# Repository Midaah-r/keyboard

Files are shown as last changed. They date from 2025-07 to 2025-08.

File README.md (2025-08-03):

# keyboard

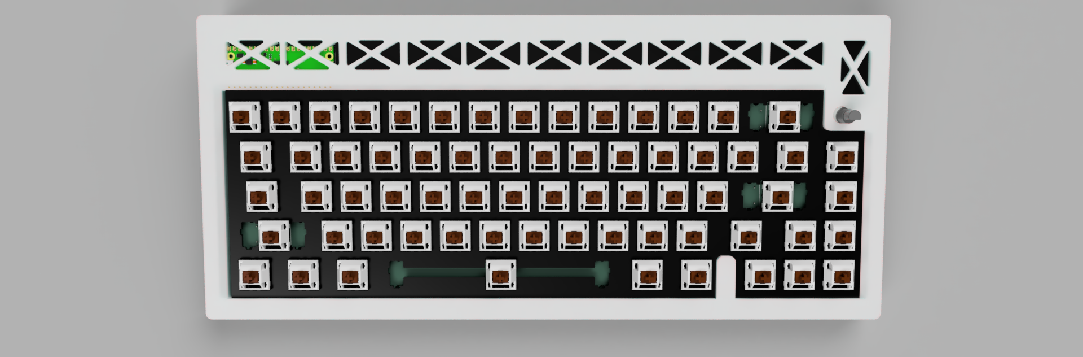
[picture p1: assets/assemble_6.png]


- compact & sleek
- 66x keys!
- Tweaked 65% layout
- 1x EC11 Rotary Encoder - For Volume, Brightness, etc
- powered by rp pico
- KMK firmware
- WOBBLY WIGGLY silkscreen

## Description

This is my first project of this scale and it was an amazing experience building this, i got to learn a lot! 

I would like to thank hackclub's hackapad tutorial, Joe Scotto and Google, you guys were my saviors.

The keyboard is a tweaked default 65% layout with one key replaced by a RE. The MCU used is Raspberry Pi Pico and the firmware used is kmk.

layout:

<image src="assets_journal/layout.png" width="400">

## PCB

**Dimensions**: 307mm x 125mm
Made inside of Kicad

| Schematic                 |
| ------------------------- |
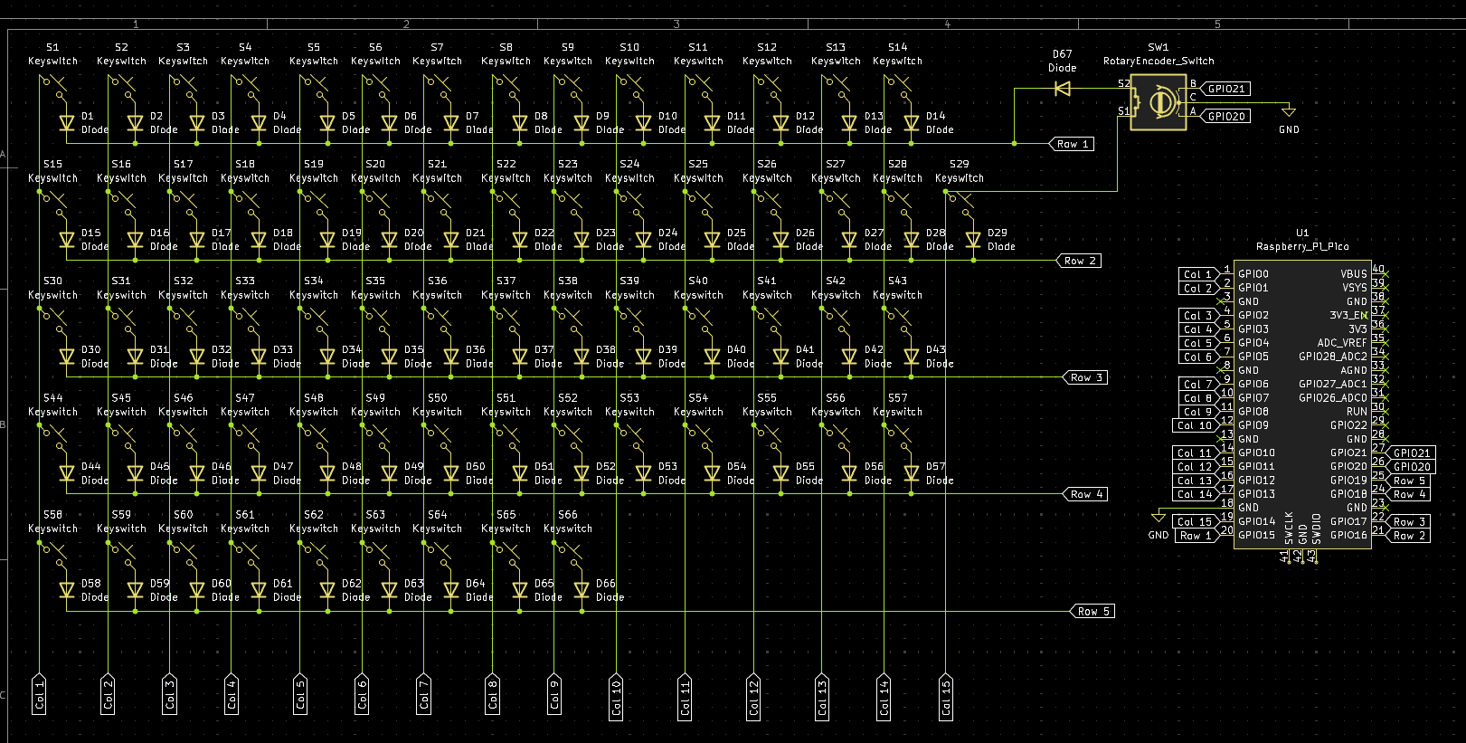
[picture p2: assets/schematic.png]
|  |

| Pcb                 |
| --------------------- |
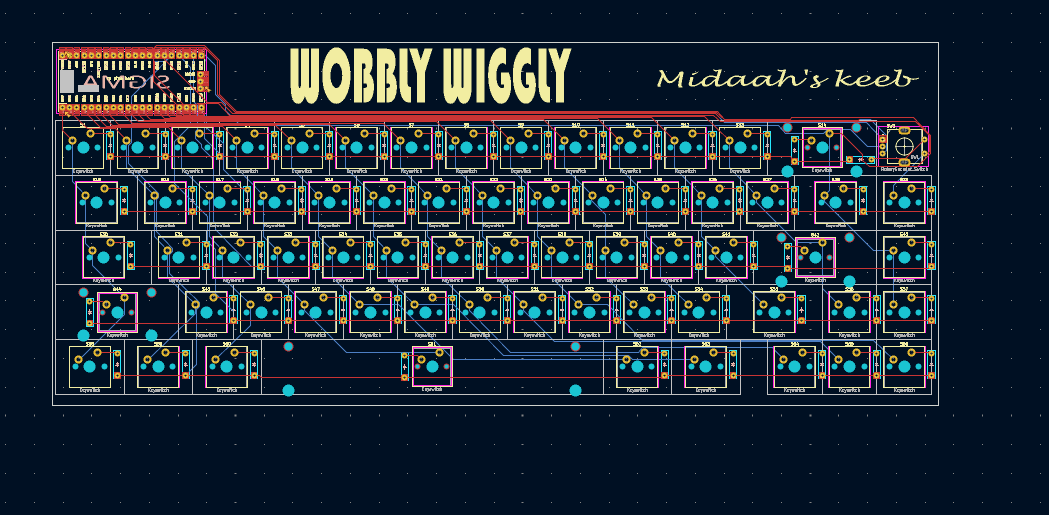
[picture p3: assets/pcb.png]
|  |

| Assembled - front             |
| ------------------------ |
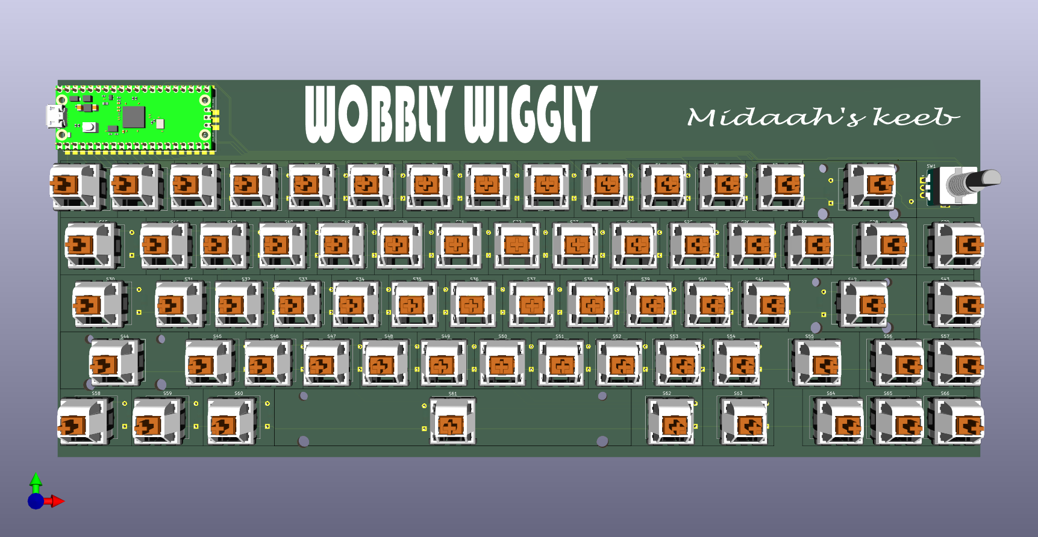
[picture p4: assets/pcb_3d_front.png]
|  |

| Assembled - Back               |
| ----------------------- |
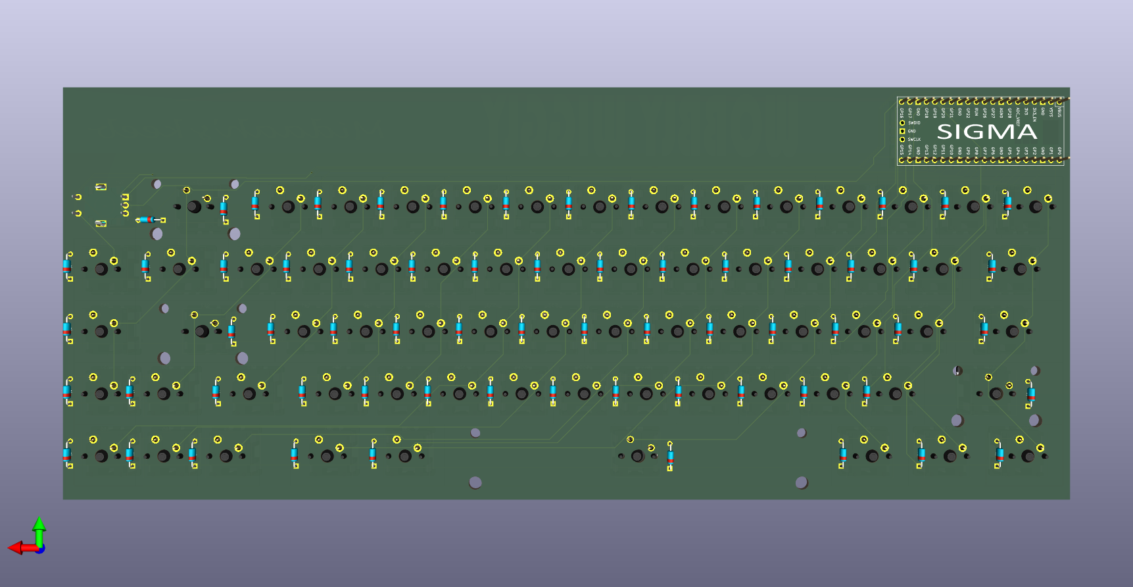
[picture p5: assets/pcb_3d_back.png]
|  |

## Case

The case was made in Fusion360.

bottom:

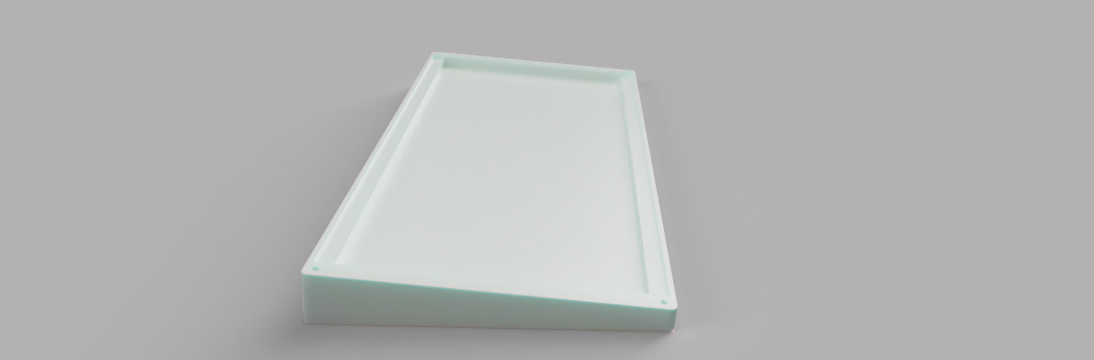
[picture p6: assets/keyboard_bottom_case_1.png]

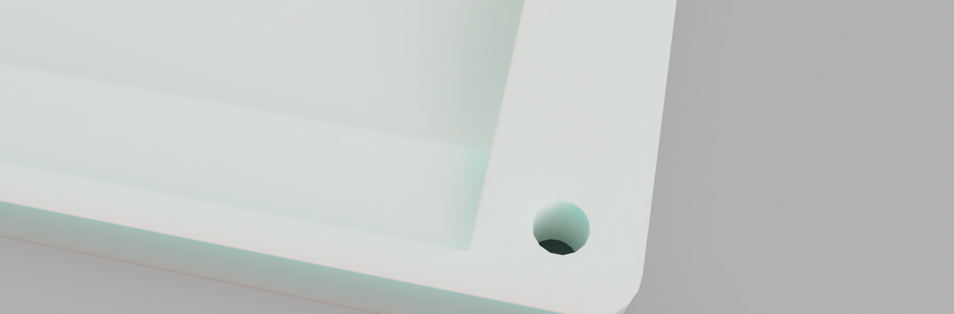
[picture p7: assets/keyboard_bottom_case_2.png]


plate:

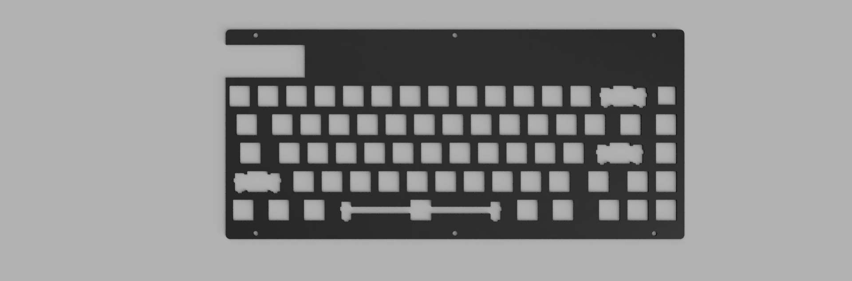
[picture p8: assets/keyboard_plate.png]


top:

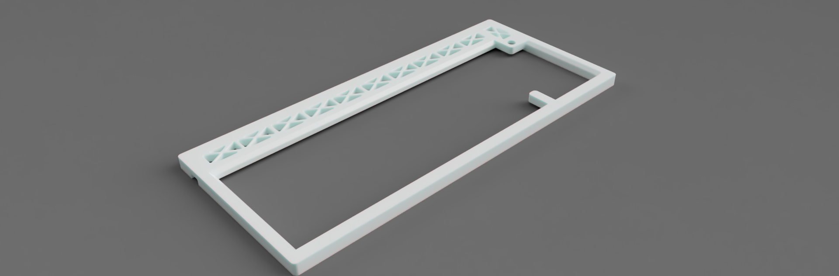
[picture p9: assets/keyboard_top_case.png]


## Assembly:

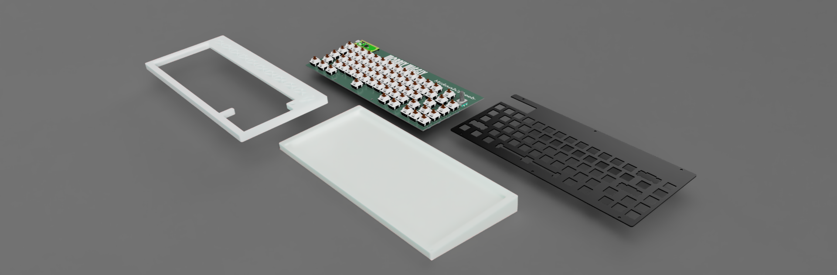
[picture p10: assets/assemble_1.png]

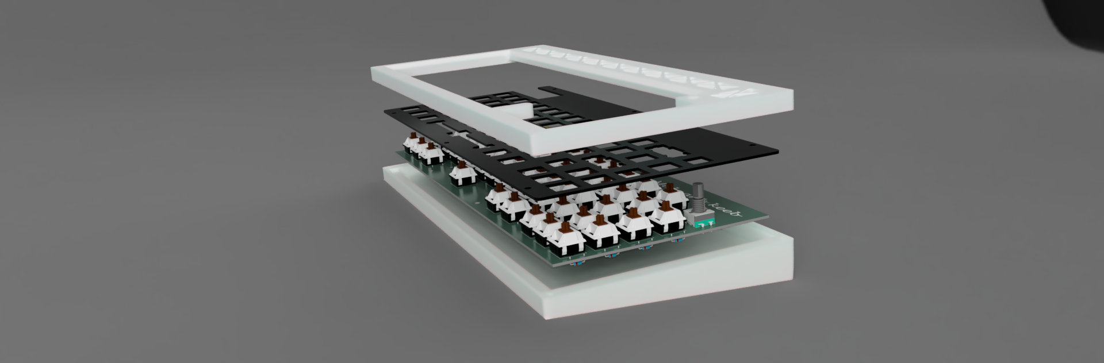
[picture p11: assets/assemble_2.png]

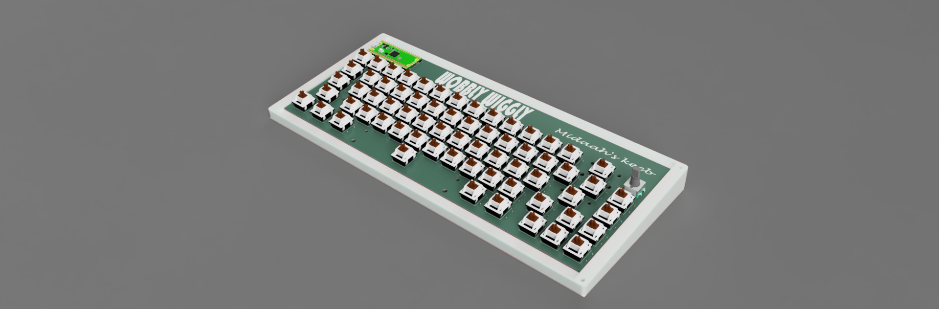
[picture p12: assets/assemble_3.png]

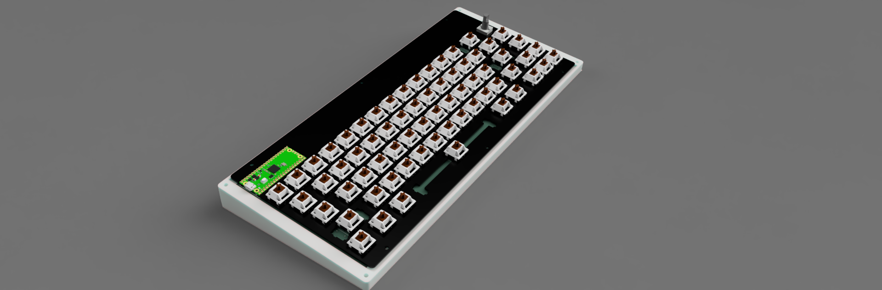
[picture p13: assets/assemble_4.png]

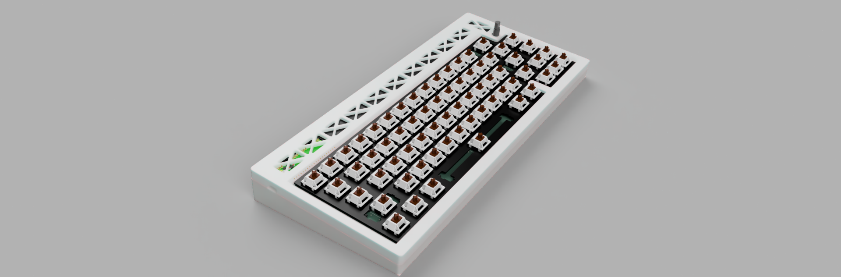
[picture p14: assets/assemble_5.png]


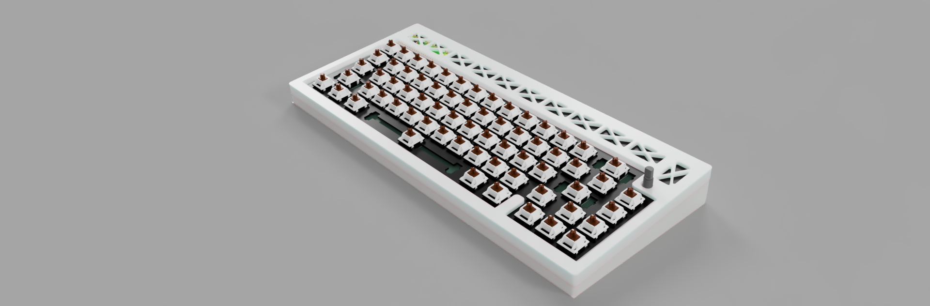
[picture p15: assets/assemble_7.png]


## Port: 

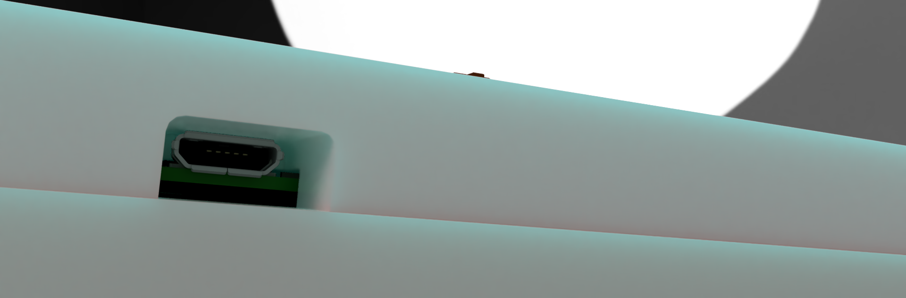
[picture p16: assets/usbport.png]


## BOM

| Name | Qty | Final Price - INR (USD) | Link |
| --- | --- | --- | --- |
| Gateron EF Grayish | 80  | 1560 ($17.79) | [here](https://neomacro.in/products/gateron-ef-grayish) |
| Cherry Profile PBT Keycaps | 1 | 1299 ($14.81) | [here](https://stackskb.com/store/veekos-gradient-keycaps-cherry-profile-135-keys/) |
| Durock Smokey Screw-In Stabilizers V2 (4+1 w/ 6.25u spacebar) | 1 | 1595 ($18.18) | [here](https://stackskb.com/store/durock-smokey-screw-in-stabilizers-v2/) |
| Diode 1N4148 Through - Hole | 80  | 176 ($2.01) | [here](https://roboticsdna.in/product/diode-1n4148/) |
| EC11 Rotary Encoder | 2 | 178 ($2.03) | [here](https://amzn.in/d/hVRxzij) |
| M3 x 16mm Allen Bolt | 25  | 170 ($1.94) | [here](https://www.amazon.in/RT-SENSE-Socket-Screws-Machine/dp/B0CX999P9J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) |
| M3 x 8mm Allen Bolt | 15  | 150 ($1.71) | [here](https://www.amazon.in/RT-SENSE-Socket-Screws-Machine/dp/B0CX99XY91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) |
| M3 x 6mm Heatset Insert | 12  | 100 ($1.14) | [here](https://www.amazon.in/M3X6-Brass-Threaded-Round-Insert/dp/B0BB86CQSJ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) |
| Raspberry Pi Pico | 1 | 384 ($4.38) | [here](https://roboticsdna.in/product/raspberry-pi-pico/) |
| Micro usb to type A cable | 2 | 580 ($6.62) | [here](https://www.amazon.in/amazon-basics-Braided-Charging-Transfer/dp/B0CH14KT9N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) |
| 4 in 1 USB hub | 1 | 200 ($2.28) | [here](https://www.amazon.in/Amazon-Multiport-Adapter-Aluminium-MacBook/dp/B0CFLT45KH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) |
| Lube (silicon dielectric grease) | 1 | 270 ($3.1) | [here](https://www.amazon.in/gp/product/B08R3NXT3B?smid=AYQOQ4F60DJ09&th=1) |
| PCB (White) | 5 | 4136.45 ($47.2) | [from jlcpcb](assets/jlcpcb_quote.png) | 
| Middle plate - 1 (White "production/MIDDLE.step") | 1 | 1276 ($14.56) | [from 3ding.in](assets/3ding_quote.png) |
| Bottom Case - 1 (White "production/BOTTOM.step") | 1 | Print Legion |
| Top Case - 1 (White "production/TOP.step") | 1 | Print Legion |
| Rotary Encoder Knob | 1 | Print Legion |
| Shipping (for diodes, MCU and Amazon) | - | 260.06 ($3) |

## Grand Total

The total sum of the parts comes to approximately inr 12335 ($141.5).

I have chosen air registered mail as the shipping option for jlcpcb as it's less likely to incurr customs thus actually being cheaper than other shipping providers.

PS: i have also included an additional USB hub and 2 microusb to type A cables because of the macropad and keyboard i wont have any space to plug the gadgets into my laptop

> **Note:** TOP and BOTTOM case parts in white, MIDDLE in black; PCB must be white.

Some componenets were ordered in packs due to unavailability (bolts, heatset inserts, etc), their prices may vary due to sales.

The final quote is subject to dollar-market trends

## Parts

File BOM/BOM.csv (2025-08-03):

Name | Qty | Final Price - INR (USD) | Link
Gateron EF Grayish | 80 | 1560 ($17.79) | https://neomacro.in/products/gateron-ef-grayish
Cherry Profile PBT Keycaps | 1 | 1299 ($14.81) | https://stackskb.com/store/veekos-gradient-keycaps-cherry-profile-135-keys/
Durock Smokey Screw-In Stabilizers V2 (4+1 w/ 6.25u spacebar) | 1 | 1595 ($18.18) | https://stackskb.com/store/durock-smokey-screw-in-stabilizers-v2/
Diode 1N4148 Through - Hole | 80 | 176 ($2.01) | https://roboticsdna.in/product/diode-1n4148/
EC11 Rotary Encoder | 2 | 178 ($2.03) | https://amzn.in/d/hVRxzij
M3 x 16mm Allen Bolt | 25 | 170 ($1.94) | https://www.amazon.in/RT-SENSE-Socket-Screws-Machine/dp/B0CX999P9J?s=industrial
M3 x 8mm Allen Bolt | 15 | 150 ($1.71) | https://www.amazon.in/RT-SENSE-Socket-Screws-Machine/dp/B0CX99XY91?s=industrial
M3 x 6mm Heatset Insert | 12 | 100 ($1.14) | https://www.amazon.in/M3X6-Brass-Threaded-Round-Insert/dp/B0BB86CQSJ?s=industrial
Raspberry Pi Pico | 1 | 384 ($4.38) | https://roboticsdna.in/product/raspberry-pi-pico/
Micro usb to type A cable | 2 | 580 ($6.62) | https://www.amazon.in/amazon-basics-Braided-Charging-Transfer/dp/B0CH14KT9N
4 in 1 USB hub | 1 | 200 ($2.28) | https://www.amazon.in/Amazon-Multiport-Adapter-Aluminium-MacBook/dp/B0CFLT45KH
Lube (silicon dielectric grease) | 1 | 270 ($3.1) | https://www.amazon.in/gp/product/B08R3NXT3B?smid=AYQOQ4F60DJ09&th=1
PCB (White) | 5 | 4136.45 ($47.2) | from jlcpcb
Middle plate - 1 (White "production/MIDDLE.step") | 1 | 1276 ($14.56) | from 3ding.in
Bottom Case - 1 (White "production/BOTTOM.step") | 1 | Print Legion
Top Case - 1 (White "production/TOP.step") | 1 | Print Legion
Rotary Encoder Knob | 1 | Print Legion
Shipping (for diodes | MCU and Amazon) | - | 260.6 ($3)

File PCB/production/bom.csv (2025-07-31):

Designator | Footprint | Quantity | Value | LCSC Part #
D1, D10, D11, D12, D13, D14, D15, D16, D17, D18, D19, D2, D20, D21, D22, D23, D24, D25, D26, D27, D28, D29, D3, D30, D31, D32, D33, D34, D35, D36, D37, D38, D39, D4, D40, D41, D42, D43, D44, D45, D46, D47, D48, D49, D5, D50, D51, D52, D53, D54, D55, D56, D57, D58, D59, D6, D60, D61, D62, D63, D64, D65, D66, D67, D7, D8, D9 | Diode_DO-35 | 67 | Diode
S1, S10, S11, S12, S13, S16, S17, S18, S19, S2, S20, S21, S22, S23, S24, S25, S26, S27, S29, S3, S31, S32, S33, S34, S35, S36, S37, S38, S39, S4, S40, S41, S43, S45, S46, S47, S48, S49, S5, S50, S51, S52, S53, S54, S56, S57, S6, S64, S65, S66, S7, S8, S9 | MX_PCB_1.00u | 53 | Keyswitch
S14 | SW_Cherry_MX_2.00u_PCB | 1 | Keyswitch
S15, S28 | MX_PCB_1.50u | 2 | Keyswitch
S30, S55 | MX_PCB_1.75u | 2 | Keyswitch
S42, S44 | SW_Cherry_MX_2.25u_PCB | 2 | Keyswitch
S58, S59, S60, S62, S63 | MX_PCB_1.25u | 5 | Keyswitch
S61 | SW_Cherry_MX_6.25u_PCB | 1 | Keyswitch
SW1 | RotaryEncoder_Alps_EC11E-Switch_Vertical_H20mm | 1 | RotaryEncoder_Switch
U1 | Raspberry_Pi_Pico | 1 | Raspberry_Pi_Pico

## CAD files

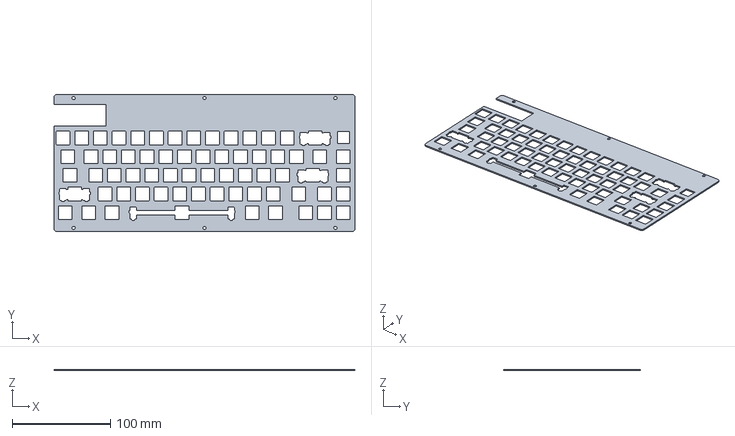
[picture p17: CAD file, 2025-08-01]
CAD/MIDDLE.step
307.0 x 140.0 x 1.50 mm

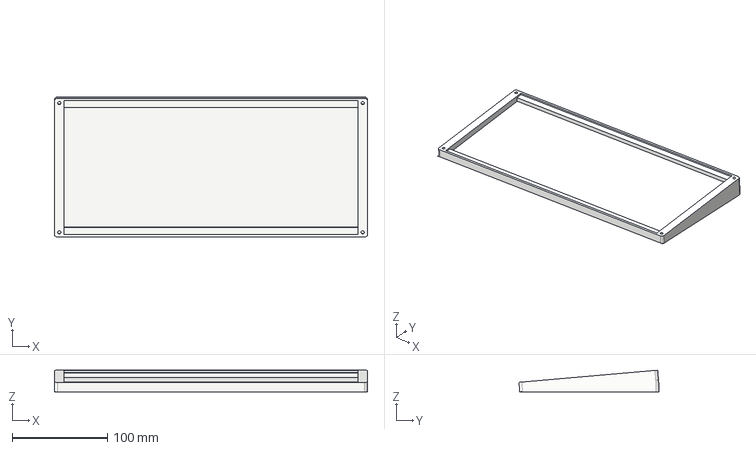
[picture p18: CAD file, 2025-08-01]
CAD/BOTTOM.step
328.0 x 146.9 x 22.7 mm

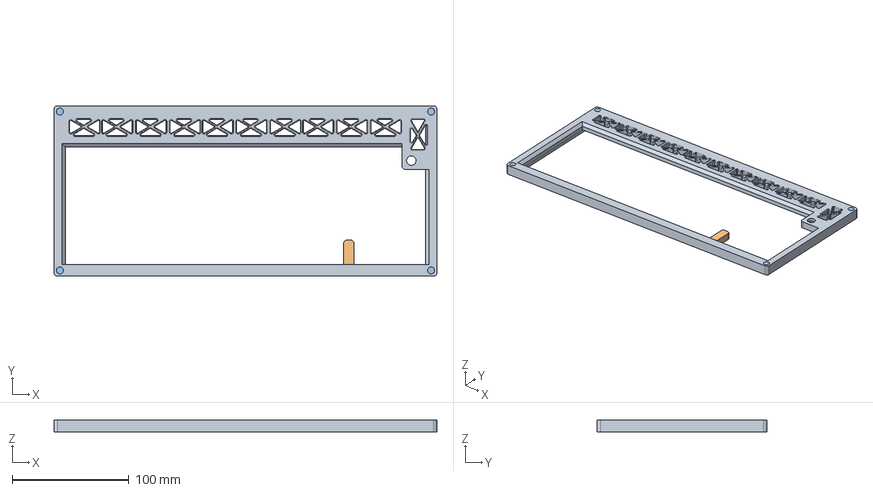
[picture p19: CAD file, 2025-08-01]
production/TOP.step
328.0 x 146.0 x 10.0 mm

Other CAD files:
CAD/STL/BOTTOM.stl
CAD/STL/MIDDLE.stl
CAD/STL/TOP.stl

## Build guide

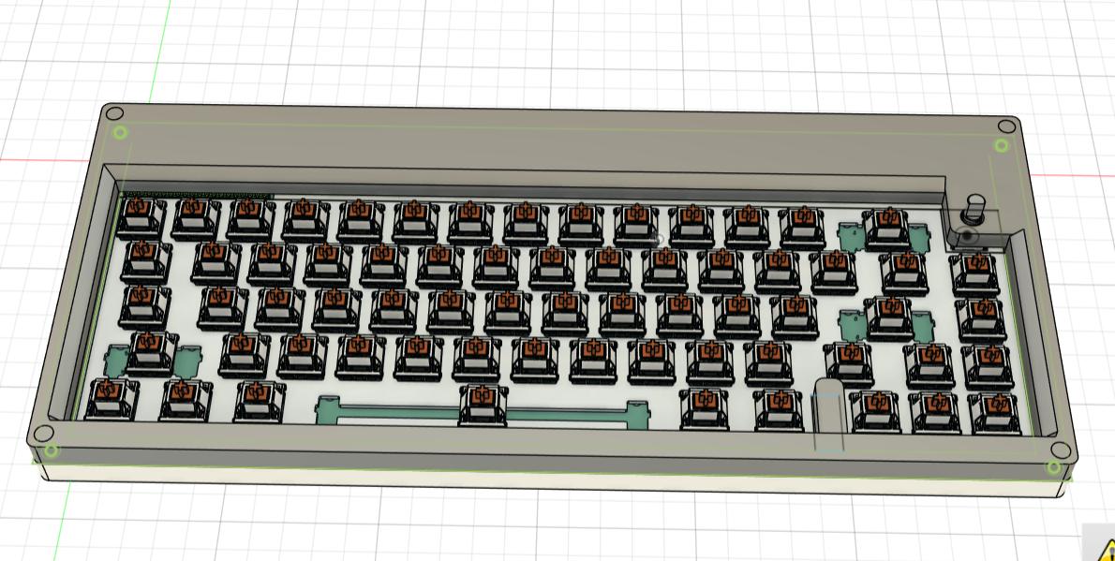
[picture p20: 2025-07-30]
assets_journal/assembled.png

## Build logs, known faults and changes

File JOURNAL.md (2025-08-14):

---
title: keyboard
author: Midaah
description: a keyboard that keyboard's
created_at: 2025-7-28
---

**total time spent: 22.5+ hours**

# keyboard 

### 27th July (day 1): reasearch and brainstorming

😭i was busy with exams and kept this project on a hold. This is my first time doing a project of this complexity and i didnt know anyhting about the workings of a mechanical keyboard and i have never owned one but.

I spent the ENTIRE (around 4 hours) day researching keyboard jargon, engineering, stabilizers, switches, parts, layouts etc... I found a few keebs for inspo

That sums up my day along with simultaneously working on my macropad (slickopad :) ) which also helped my understand the working and workflow better.

<image src="assets_journal/notion.jpg" width="400">

Suuuuper professional research notes:

<image src="assets_journal/notes.jpg" width="400">

**Time Spent:** 4 hours

---

### 29th July (day 2): design, schematic and pcb

I FORGOT TO ENTER MY PREVIOUS DAY cos i had to attend a family event :( but here goes 

spent the previous day and today finalizing the layout, i wanted a cute, compact keyboard so i decided to go with a 65% keyboard layout, the top right key replaced with a RE:

<image src="assets_journal/layout.png" width="400">

for the MCU i decided to go for a raspberry pi pico, cos its simple, fairly cheap and readily available. 

This is my first pcb of this scale so it took quite a bit of research (the macropad helped tons). i decided to go for a 15x5 key matrix with diodes to prevent ghosting coming to a total of 66 keys and 1 RE. here is the schematic (took me less time than i expected me to) i came up with:

<image src="assets_journal/schematic.png" width="400">

I HATE ROUTING, while making my macropad i rerouted a couple hundered of times. but THIS TIME I HAD A FIXED LAYOUT IN MIND and as a result i didnt have to reroute much. Im sooo happy that my routing went smoothly. i had to use 2-3 vias but i tried to make do without. here is the pcb:

<image src="assets_journal/pcb.png" width="400">

finally here's a 3d render of the pcb (LOOKS REALLY COOOOOL!!!)

<image src="assets_journal/pcb_3d.png" width="400">

Im really happy with the progress ive made although i wasted quite a bit of time finding the right footprints and models and figuring out (googling) other teeny tiny issues but now i can do stuff without tutorials now and im proud of that.

I'll start designing the case tomorrow!! (3d modelling is nightmare fuel)

**Time Spent:**  4.5 hours

---

### 30th July (day 3): CAD - case

_wheeeeezeee_

I truly hate fusion navigation controls, controlling a 3d space with a 2d cursor is hard, anyhow....

I COMPLETELY LOCKED IN TODAY! 

After researching about keyboard mounts, i wanted to go for a gasket mount or gummy-o-ring mount, but both of those sounded a bit complex and i didnt know if i could find the gaskets separately, sooo, i chose to go for a top mount design as i read its a good balance and is reallly popular.

Im using heatset inserts this time and i want to conceal the screws so i kept that in mind.

This is what i came up with, although i might need to tweak it a bit tomorrow:

bottom case:

<image src="/assets_journal/bottom_case.png" width="400">

plate: 

<image src="assets_journal/plate.png" width="400">

top case:

<image src="assets_journal/top_case.png" width="400">

final assembled look: 

<image src="assets_journal/assembled.png" width="1000">

Although im happy with how it turned out, i dont like the massive 40mm unused space on the top, i wanted to make a minimal keyboard and this goes completely against, the only solution i found feasible was to use solder pads and then use wires to link the pcb to the MCU, but this is my first time with something like this and i thought its better not to experiment too much, moreover, i have a deadline, ie, tomorrow!

Ill do the finishing touches and fix up any errors tomorrow and get my repo ready tomorrow hopefully!

BTW!!! My macropad got approved today!! YIPPEEE!

**Time spent:** 8 hours

---

### 31st July (day 4): finishing touches

I made a few tweaks here and there. adjuested somedimensions. changed some filleted edges to chamfered cos i read that it is better for 3d printing. 

I spent quite some time rendering the various views.

This project was amazing and it was the most complicated project i have ever taken. This was a new learning experience for me and i;m so happy! Im quite happy with how it turned out

I'll now make the final repo and then submit!

Thank you

**Time Spent:**  2 hours

---

### 1st July (day 5): Top case redesign

The case was a bit simple and i was told to make it a more complicated. so i decided to go with a wing embossing on the top part of the case

I decided to make an angel wing like design in figma 

<image src="assets_journal/wings_figma.png" width="400">

after embossing it on , this is how it turned out:

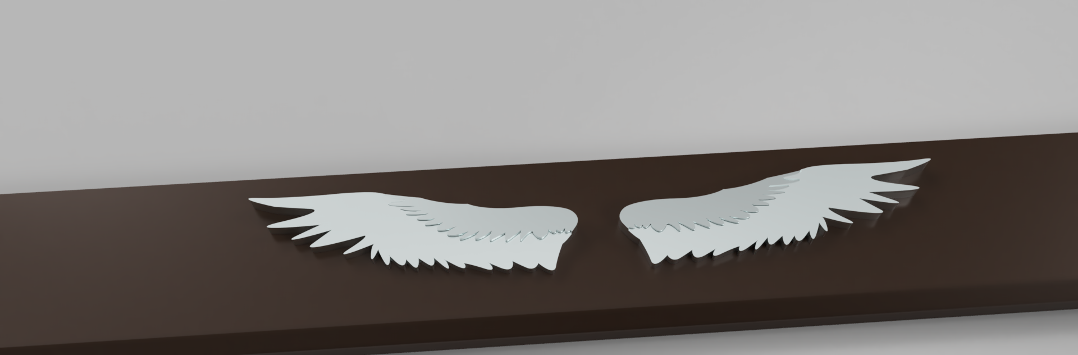
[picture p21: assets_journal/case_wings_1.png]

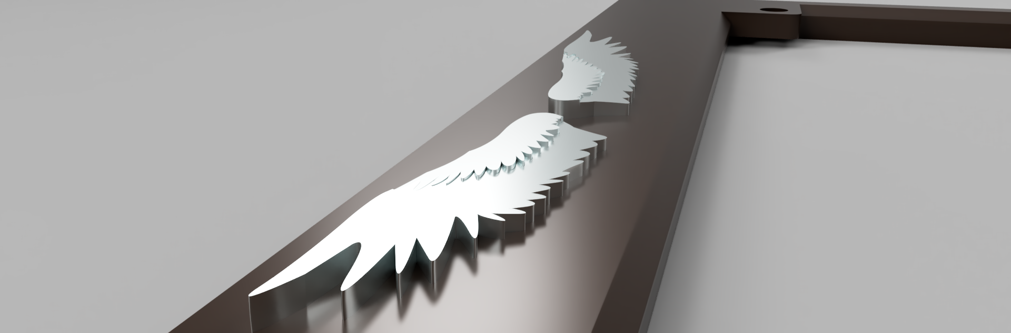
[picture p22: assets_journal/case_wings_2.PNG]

 
I think it looks pretty cool, idts its gonna look after the 3d print tho.

**Time Spent**: 1 hour

---

### 2nd July (day 6): Top Case redesign and general tweaks

_bruh_

I redesigned the case again and this time and after a _LOT_ of trail and error with different ideas i decided to go with a cool hollow net like design. It took me an embarrasingly long time to implement it courtesy of my poor fusion skills :D 

This is how it turned out:

<image src="assets_journal/case_net_raw.png" width="400">

these are the renders:

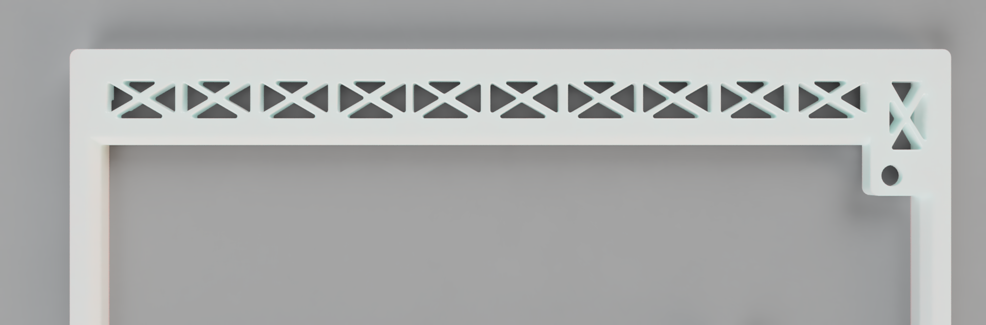
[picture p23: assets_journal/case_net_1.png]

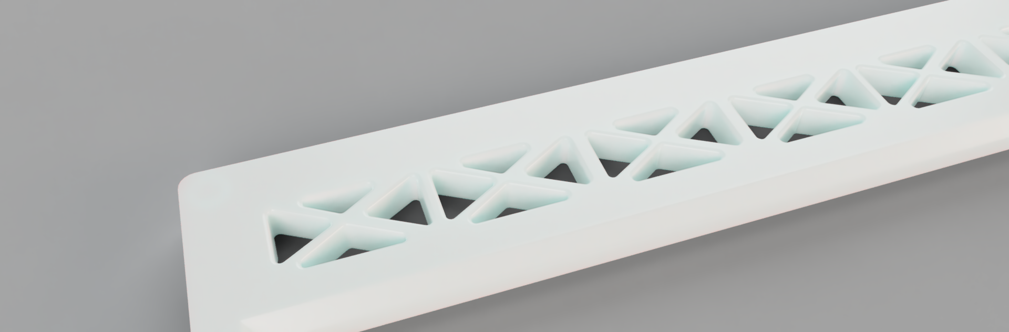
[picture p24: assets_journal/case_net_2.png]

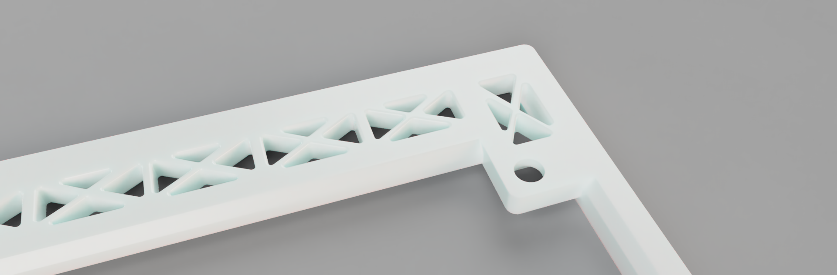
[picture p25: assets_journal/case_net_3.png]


I'm pretty happy with this, i think it looks cool and idts there'll be any issues 3d printing this.

also i forgot to add one hole for the heatset insert 

<image src="assets_journal/mistake_1.png" width="400">

and i made a bit of square space for the RE as i was concerned itll not fit

<image src="assets_journal/RE_square.png" width="400">

I hope its done now, i think this is perfect now!

***Time spent***: 3 hours

### 12th July: Added _COOL_ Silkscreen and placed orders

wooh 

My grant arrived a few days ago and since ive placed orders for mostly everything. 

only the case remains of which each part needs to be split into two to make it 3d printable in a typical 256mm<sup>3</sup> 3d printer.

Anyways! here is how the pcb looks: 

front:
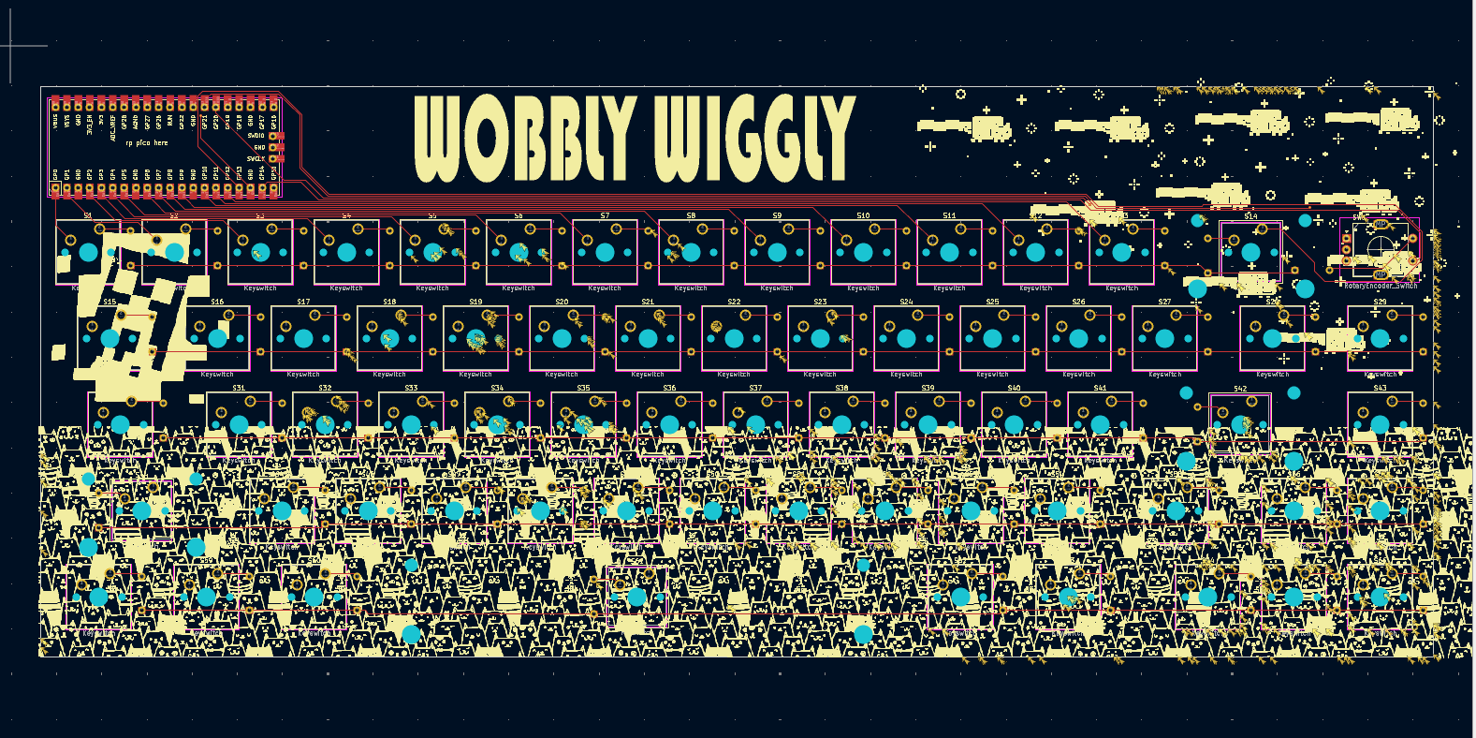
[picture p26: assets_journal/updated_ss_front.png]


back:
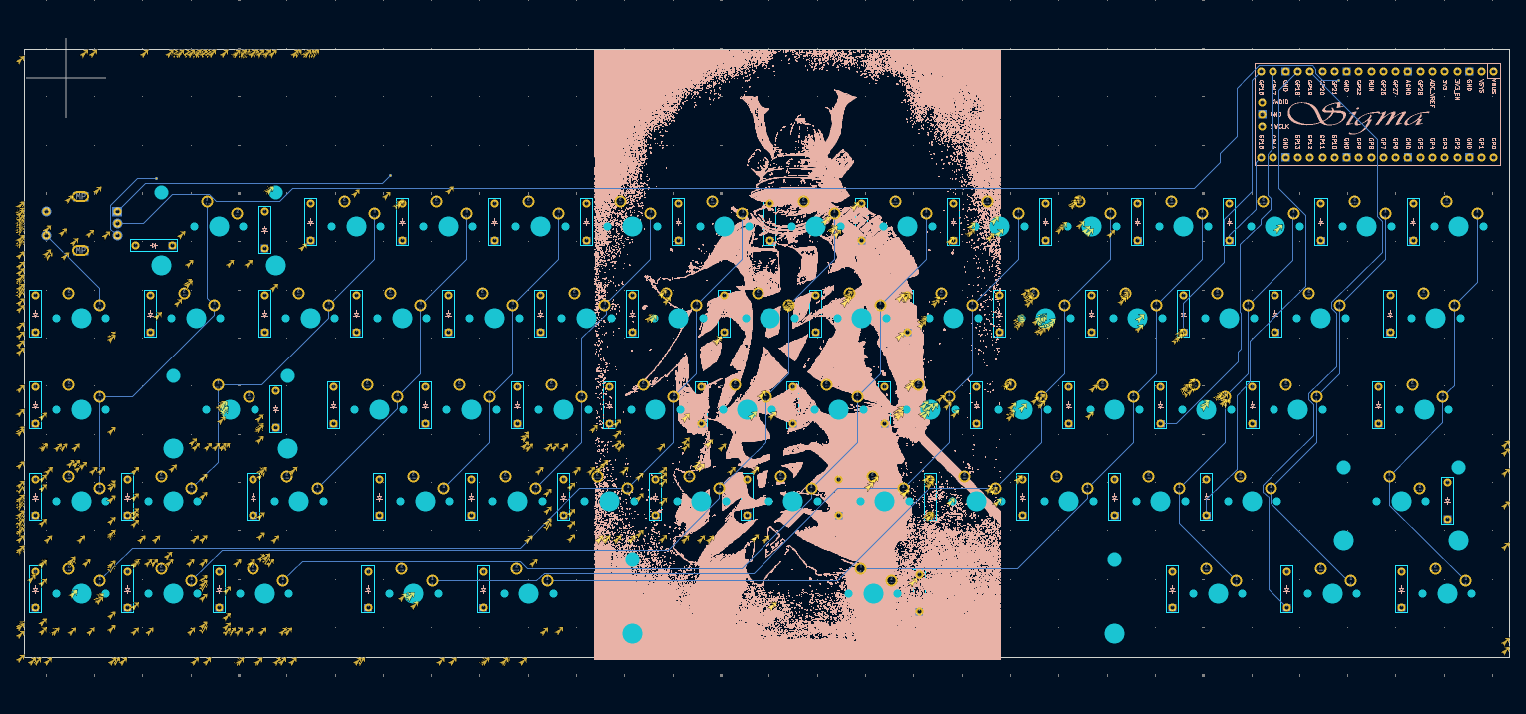
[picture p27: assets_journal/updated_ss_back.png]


3d: 
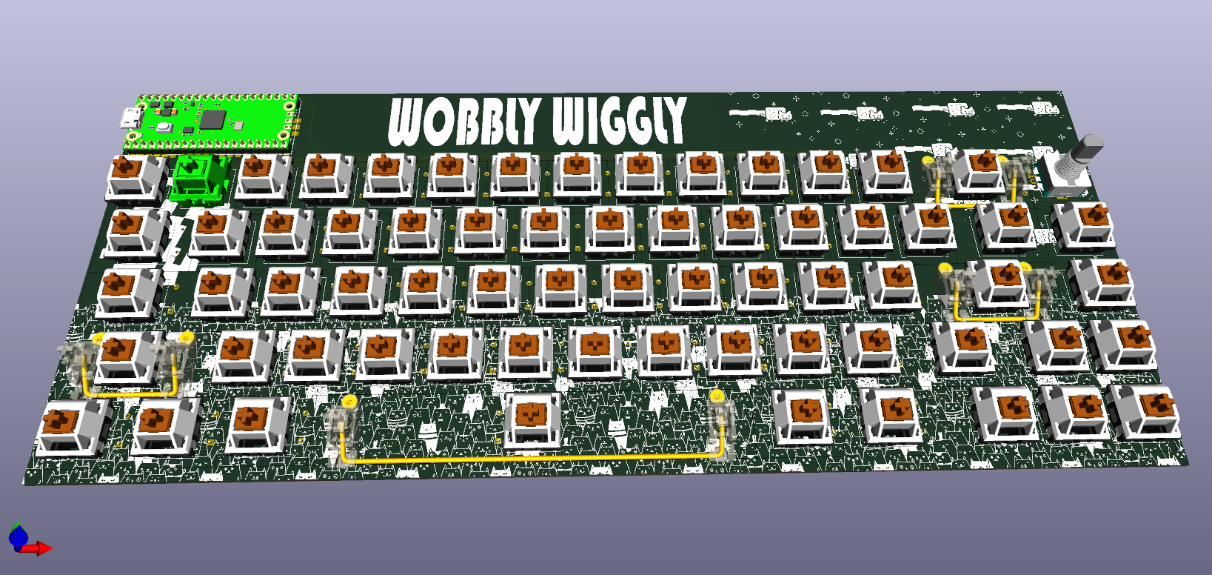
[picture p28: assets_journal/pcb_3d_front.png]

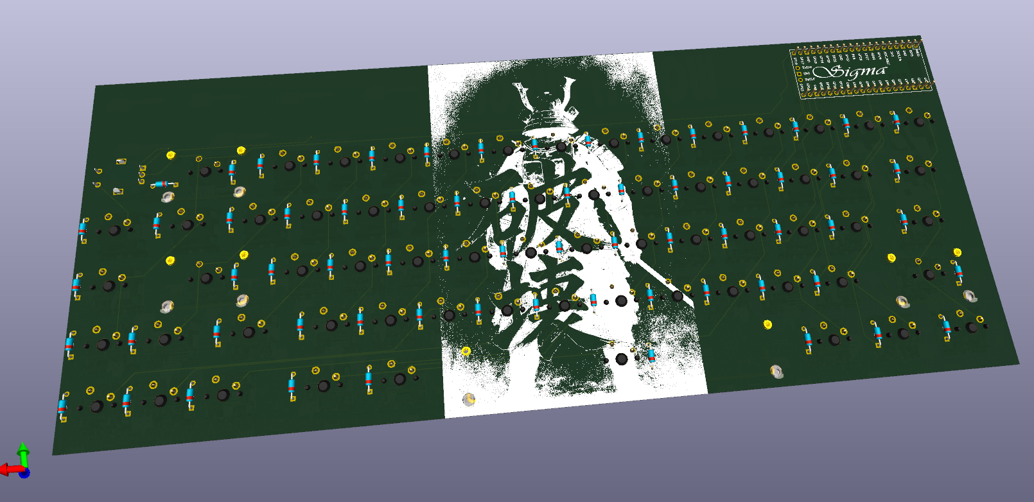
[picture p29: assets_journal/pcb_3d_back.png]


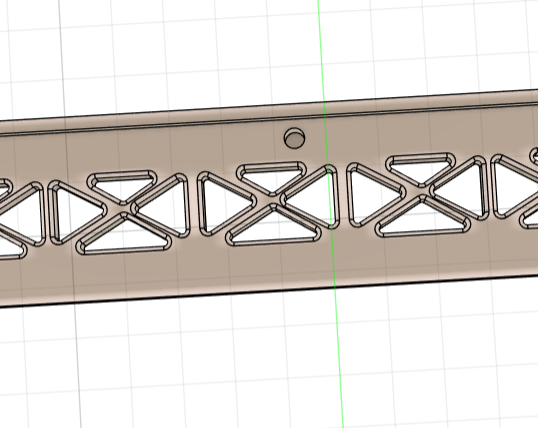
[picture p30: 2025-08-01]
assets_journal/mistake_1.png

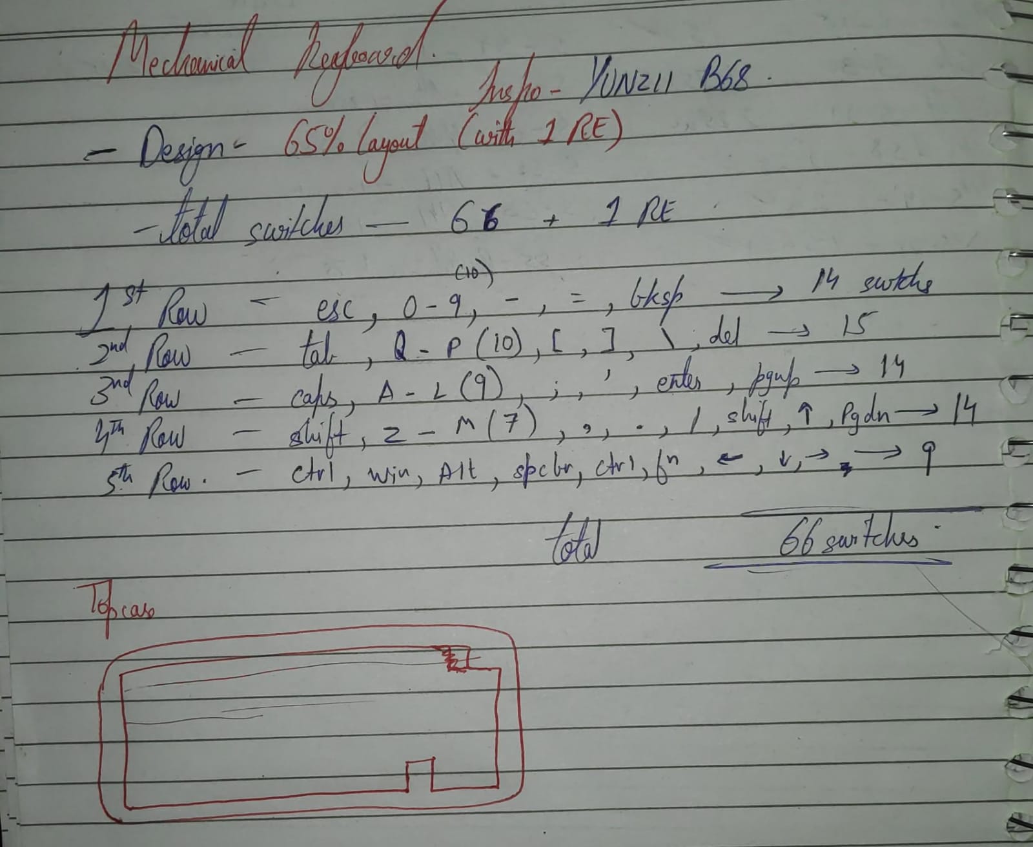
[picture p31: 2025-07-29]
assets_journal/notes.jpg

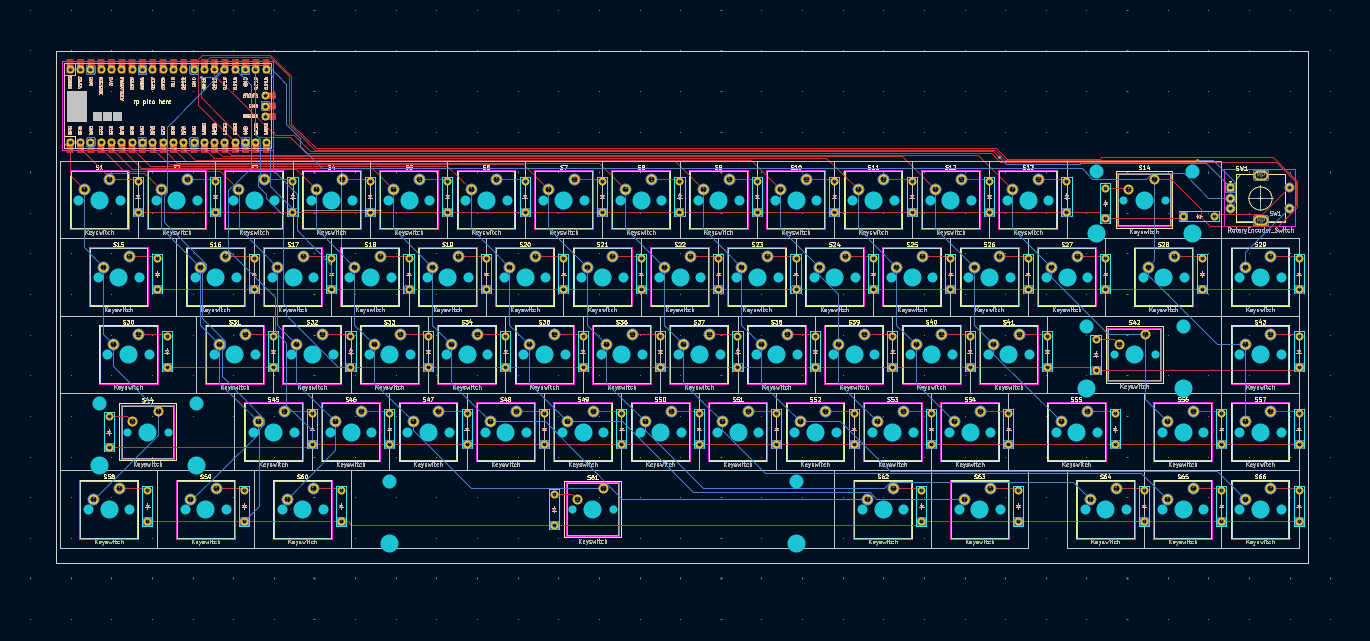
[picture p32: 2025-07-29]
assets_journal/pcb.png

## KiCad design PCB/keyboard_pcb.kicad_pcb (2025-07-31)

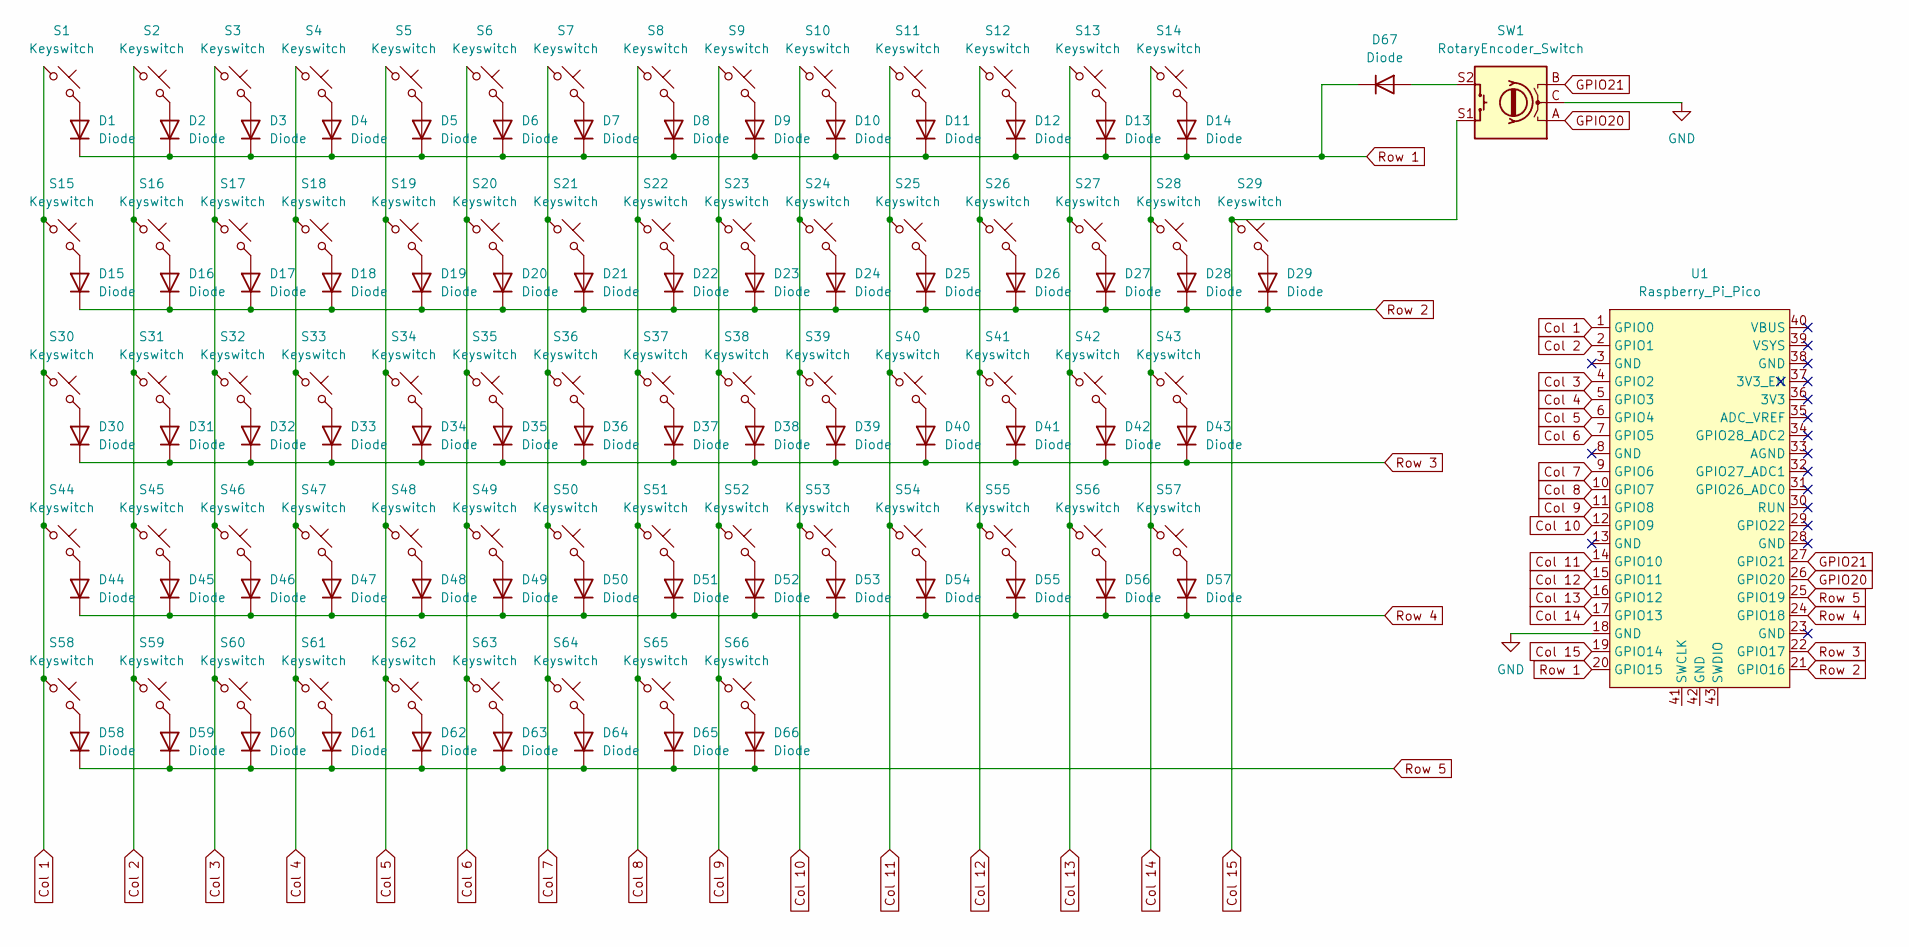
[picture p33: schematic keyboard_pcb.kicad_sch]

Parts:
D1, D2, D3, D4, D5, D6, D7, D8, D9, D10, D11, D12, D13, D14, D15, D16, D17, D18, D19, D20, D21, D22, D23, D24, D25, D26, D27, D28, D29, D30, D31, D32, D33, D34, D35, D36, D37, D38, D39, D40, D41, D42, D43, D44, D45, D46, D47, D48, D49, D50, D51, D52, D53, D54, D55, D56, D57, D58, D59, D60, D61, D62, D63, D64, D65, D66, D67: Diode; Diode_DO-35
S1, S2, S3, S4, S5, S6, S7, S8, S9, S10, S11, S12, S13, S16, S17, S18, S19, S20, S21, S22, S23, S24, S25, S26, S27, S29, S31, S32, S33, S34, S35, S36, S37, S38, S39, S40, S41, S43, S45, S46, S47, S48, S49, S50, S51, S52, S53, S54, S56, S57, S64, S65, S66: Keyswitch; MX_PCB_1.00u
S14: Keyswitch; SW_Cherry_MX_2.00u_PCB
S15, S28: Keyswitch; MX_PCB_1.50u
S30, S55: Keyswitch; MX_PCB_1.75u
S42, S44: Keyswitch; SW_Cherry_MX_2.25u_PCB
S58, S59, S60, S62, S63: Keyswitch; MX_PCB_1.25u
S61: Keyswitch; SW_Cherry_MX_6.25u_PCB
SW1: RotaryEncoder_Switch; RotaryEncoder_Alps_EC11E-Switch_Vertical_H20mm
U1: Raspberry_Pi_Pico

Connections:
Col 1: S1.1, S15.1, S30.1, S44.1, S58.1, U1.1 (GPIO0)
Col 2: S2.1, S16.1, S31.1, S45.1, S59.1, U1.2 (GPIO1)
Col 3: S3.1, S17.1, S32.1, S46.1, S60.1, U1.4 (GPIO2)
Col 4: S4.1, S18.1, S33.1, S47.1, S61.1, U1.5 (GPIO3)
Col 5: S5.1, S19.1, S34.1, S48.1, S62.1, U1.6 (GPIO4)
Col 6: S6.1, S20.1, S35.1, S49.1, S63.1, U1.7 (GPIO5)
Col 7: S7.1, S21.1, S36.1, S50.1, S64.1, U1.9 (GPIO6)
Col 8: S8.1, S22.1, S37.1, S51.1, S65.1, U1.10 (GPIO7)
Col 9: S9.1, S23.1, S38.1, S52.1, S66.1, U1.11 (GPIO8)
Col 10: S10.1, S24.1, S39.1, S53.1, U1.12 (GPIO9)
Col 11: S11.1, S25.1, S40.1, S54.1, U1.14 (GPIO10)
Col 12: S12.1, S26.1, S41.1, S55.1, U1.15 (GPIO11)
Col 13: S13.1, S27.1, S42.1, S56.1, U1.16 (GPIO12)
Col 14: S14.1, S28.1, S43.1, S57.1, U1.17 (GPIO13)
Col 15: S29.1, SW1.S1, U1.19 (GPIO14)
GND: SW1.C, U1.18 (GND)
GPIO20: SW1.A, U1.26 (GPIO20)
GPIO21: SW1.B, U1.27 (GPIO21)
unnamed: D1.2 (A), S1.2
unnamed: D2.2 (A), S2.2
unnamed: D3.2 (A), S3.2
unnamed: D4.2 (A), S4.2
unnamed: D5.2 (A), S5.2
unnamed: D6.2 (A), S6.2
unnamed: D7.2 (A), S7.2
unnamed: D8.2 (A), S8.2
unnamed: D9.2 (A), S9.2
unnamed: D10.2 (A), S10.2
unnamed: D11.2 (A), S11.2
unnamed: D12.2 (A), S12.2
unnamed: D13.2 (A), S13.2
unnamed: D14.2 (A), S14.2
unnamed: D15.2 (A), S15.2
unnamed: D16.2 (A), S16.2
unnamed: D17.2 (A), S17.2
unnamed: D18.2 (A), S18.2
unnamed: D19.2 (A), S19.2
unnamed: D20.2 (A), S20.2
unnamed: D21.2 (A), S21.2
unnamed: D22.2 (A), S22.2
unnamed: D23.2 (A), S23.2
unnamed: D24.2 (A), S24.2
unnamed: D25.2 (A), S25.2
unnamed: D26.2 (A), S26.2
unnamed: D27.2 (A), S27.2
unnamed: D28.2 (A), S28.2
unnamed: D29.2 (A), S29.2
unnamed: D30.2 (A), S30.2
unnamed: D31.2 (A), S31.2
unnamed: D32.2 (A), S32.2
unnamed: D33.2 (A), S33.2
unnamed: D34.2 (A), S34.2
unnamed: D35.2 (A), S35.2
unnamed: D36.2 (A), S36.2
unnamed: D37.2 (A), S37.2
unnamed: D38.2 (A), S38.2
unnamed: D39.2 (A), S39.2
unnamed: D40.2 (A), S40.2
unnamed: D41.2 (A), S41.2
unnamed: D42.2 (A), S42.2
unnamed: D43.2 (A), S43.2
unnamed: D44.2 (A), S44.2
unnamed: D45.2 (A), S45.2
unnamed: D46.2 (A), S46.2
unnamed: D47.2 (A), S47.2
unnamed: D48.2 (A), S48.2
unnamed: D49.2 (A), S49.2
unnamed: D50.2 (A), S50.2
unnamed: D51.2 (A), S51.2
unnamed: D52.2 (A), S52.2
unnamed: D53.2 (A), S53.2
unnamed: D54.2 (A), S54.2
unnamed: D55.2 (A), S55.2
unnamed: D56.2 (A), S56.2
unnamed: D57.2 (A), S57.2
unnamed: D58.2 (A), S58.2
unnamed: D59.2 (A), S59.2
unnamed: D60.2 (A), S60.2
unnamed: D61.2 (A), S61.2
unnamed: D62.2 (A), S62.2
unnamed: D63.2 (A), S63.2
unnamed: D64.2 (A), S64.2
unnamed: D65.2 (A), S65.2
unnamed: D66.2 (A), S66.2
unnamed: D67.2 (A), SW1.S2
Row 1: D1.1 (K), D2.1 (K), D3.1 (K), D4.1 (K), D5.1 (K), D6.1 (K), D7.1 (K), D8.1 (K), D9.1 (K), D10.1 (K), D11.1 (K), D12.1 (K), D13.1 (K), D14.1 (K), D67.1 (K), U1.20 (GPIO15)
Row 2: D15.1 (K), D16.1 (K), D17.1 (K), D18.1 (K), D19.1 (K), D20.1 (K), D21.1 (K), D22.1 (K), D23.1 (K), D24.1 (K), D25.1 (K), D26.1 (K), D27.1 (K), D28.1 (K), D29.1 (K), U1.21 (GPIO16)
Row 3: D30.1 (K), D31.1 (K), D32.1 (K), D33.1 (K), D34.1 (K), D35.1 (K), D36.1 (K), D37.1 (K), D38.1 (K), D39.1 (K), D40.1 (K), D41.1 (K), D42.1 (K), D43.1 (K), U1.22 (GPIO17)
Row 4: D44.1 (K), D45.1 (K), D46.1 (K), D47.1 (K), D48.1 (K), D49.1 (K), D50.1 (K), D51.1 (K), D52.1 (K), D53.1 (K), D54.1 (K), D55.1 (K), D56.1 (K), D57.1 (K), U1.24 (GPIO18)
Row 5: D58.1 (K), D59.1 (K), D60.1 (K), D61.1 (K), D62.1 (K), D63.1 (K), D64.1 (K), D65.1 (K), D66.1 (K), U1.25 (GPIO19)

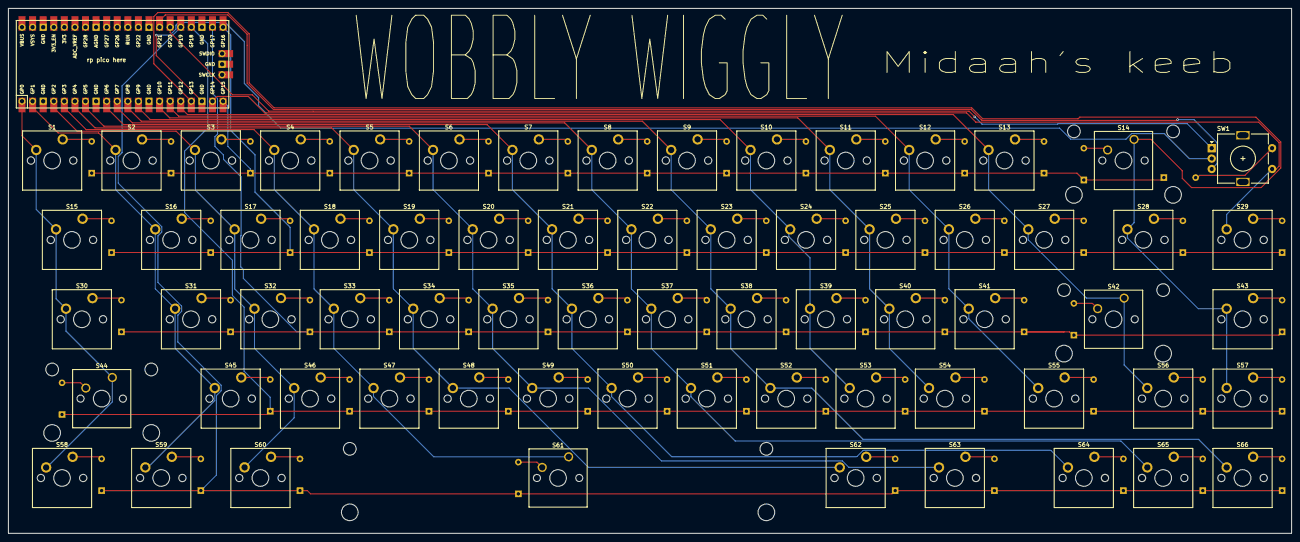
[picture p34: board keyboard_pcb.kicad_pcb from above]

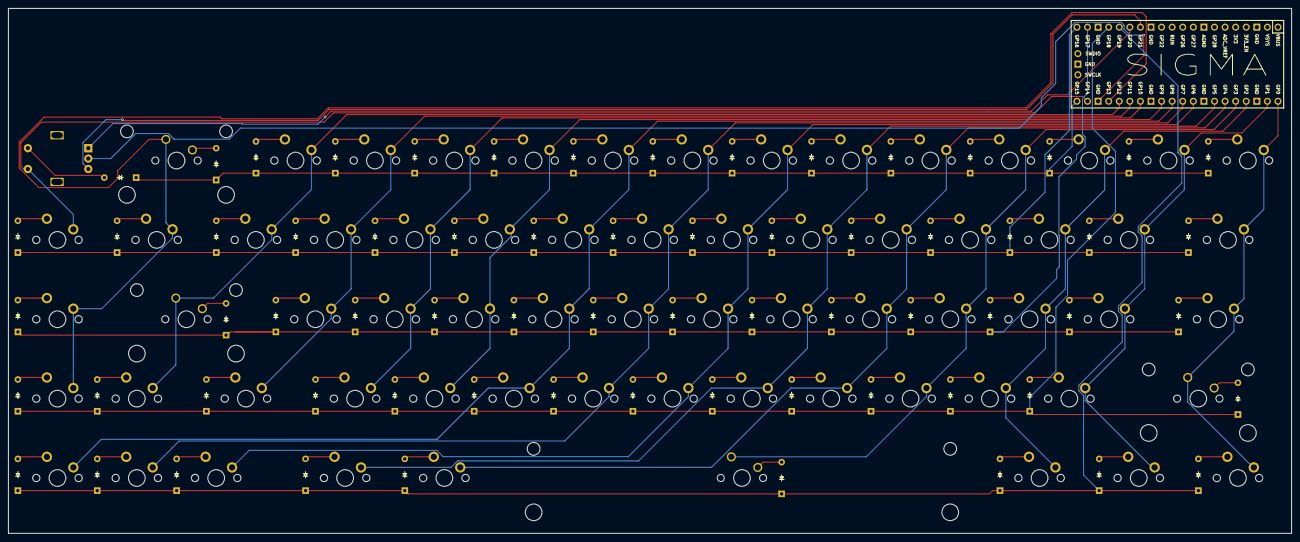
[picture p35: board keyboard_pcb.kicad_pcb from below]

Board: 2 copper layers, 308.0 x 126.0 mm, 135 parts (67 on the bottom side), 90 nets.

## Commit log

2025-07-30 fixed minor errors JOURNAL.md
    typed jpg instead of png. im tired today....
2025-07-31 added CAD, production, PCB, assets and day4 of journal
    [BOTTOM.step, BOTTOM.stl, MIDDLE.step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]
2025-07-31 Added BOM.csv
    [BOM.csv]
2025-07-31 Updated BOM
    [BOM.csv]
2025-08-01 Made final changes to CAD, production and added new assets
    [BOTTOM.step, MIDDLE.step, TOP.step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]
2025-08-02 updated BOM for shipping
    [BOM.csv]
2025-08-03 update BOM
    [BOM.csv]
2025-08-12 updated pcb related folders/files and added journal entry
    [designators.csv]
